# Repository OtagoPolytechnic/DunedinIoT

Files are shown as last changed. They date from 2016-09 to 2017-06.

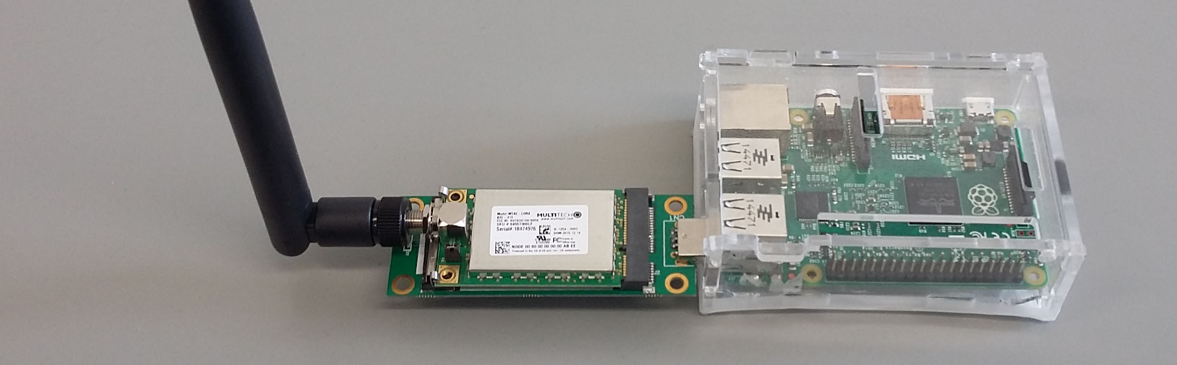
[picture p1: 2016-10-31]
images/gateway_hardware.jpg

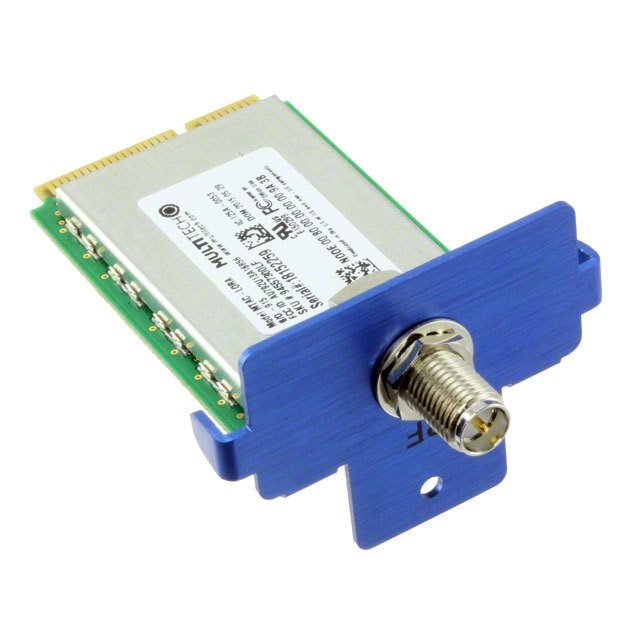
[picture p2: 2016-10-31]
images/mCard.jpg

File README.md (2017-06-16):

---
layout: default
title: Home
---

# IoT Dunedin

## What is the Internet of Things?
The Internet of Things is the inter-networking of devices such as smart devices, sensors, software, and other items embedded with electronics.
Connecting these devices to a network creates the Internet of Things and enables the collection and exchange of data between devices and server. 
This data can then be used accessed and used by an end user. Although very similar, this is not to be confused by wifi. The IoT uses slightly 
different technology to achieve *this*. Our Iot solution is implemented using LoRaWAN.

## LoRaWAN Network
LoRaWAN is a low-power, long-range wide area network standard devised by the LoRa Alliance.
It is intended for long-life, battery operated sensor devices to communicate sensed data to a central server via one or more internet-connected gateway devices capable of receiving radio transmissions.

## Our Goal:
To research and develop an open LoRaWAN consisting of one or more gateway devices, multiple sensor devices, and a central server. All of this in the central Dunedin area, to provide access to user data for use in custom mobile/web/desktop applications.

### Current Status:
Testing prototype working, but not on the right frequencies. 

### Future Plan:
Move prototype to new hardware and onto the right frequencies. (Next semester).

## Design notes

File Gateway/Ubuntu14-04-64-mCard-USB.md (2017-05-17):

# Ubuntu Trusty (14.04) with Lora mCard - Preparing a test gateway host in a VirtualBox VM

## Prep:
* Install VirtualBox.
* In VirtualBox VM manager, install an Ubuntu 14.04 install as usual. Server version is fine unless you want a GUI.
* Plug Mcard/USB into PC.
* Select virtual machine, click settings, click USB, add a USB device filter for FDTI device.

-----------------

## Set up:
1. Install 32 bit ftdi drivers to talk to the mCard:

`sudo apt-get install libftdi1:i386`

-----------------

2. Install 32 SSL 1.0.2 installed, supplied by 3rd party repository:

`openssl version -a`

`sudo add-apt-repository ppa:0k53d-karl-f830m/openssl`

`sudo apt-get update`

`sudo apt-get install openssl`

`openssl version -a`

-----------------

3. Download the libmpsse source and compile/install :

`sudo apt-get install swig libftdi-dev python-dev`

`wget https://github.com/devttys0/libmpsse/archive/master.zip -O libmpsse.zip`

`unzip libmpsse.zip`

`cd libmpsse-master`

`cd src`

`./configure`

`make`

`sudo make install`

-----------------

4. Unplug card, power off VM, replug card, and power on VM.

The gateway is now ready for packet forwarding software, for example:

To test with Loriot:

 Open a terminal and get the Loriot binary address (it's different for every server, this gateway is registered on us1.loriot.io )

`sudo mkdir /lrt`

`sudo chmod 777 /lrt`

`cd /lrt`

`wget http://us1.loriot.io/home/gwsw/loriot-linux-x64-mcard-USB-0-latest.bin -O loriot-gw`

`chmod +x loriot-gw`

`cd /lrt`

`sudo ./loriot-gw -f`

---------------

## Notable problems:
* Without SSL 1.0.2 there will be an error.
* Without install the i386 (32 bit) FTDI drivers there wiill be an error message about a missing .so file.
* Gateway terminal will log 404 errors if gateway MAC is not properly  registered with Loriot (or other provider).
* There was an error message and LIBMPSSE code saying "you could be running an incompatible version of the binary" after installing another LIBMPSSE version. That version was replaced with the version above and after restarting the hardware the gateway was active.

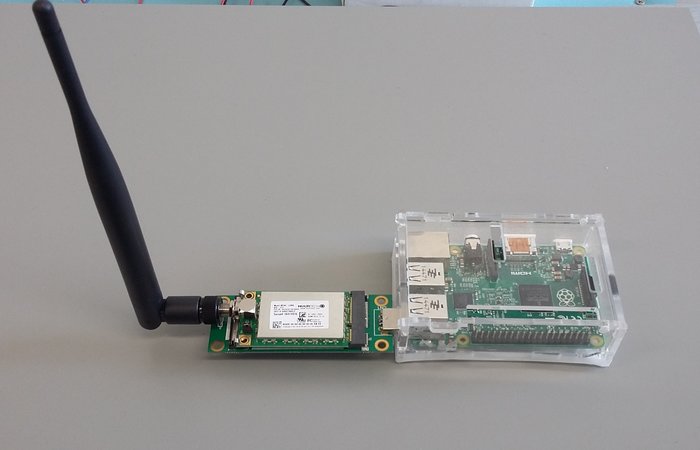
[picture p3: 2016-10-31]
images/GW_tmb.jpg

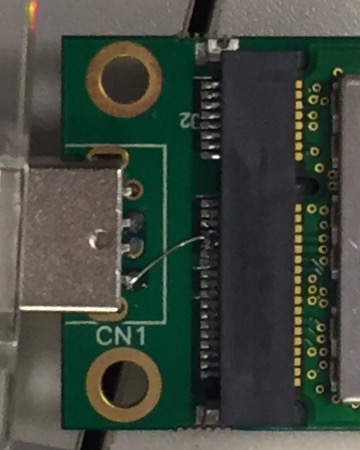
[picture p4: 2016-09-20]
images/gateway1.jpg

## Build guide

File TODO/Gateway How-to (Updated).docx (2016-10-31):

Creating a LoRaWAN Gateway

There are many options you can pursue when choosing the hardware to use for LoRaWAN applications. You can choose to simply buy the pre-made TTN Gateway directly from TTN themselves, or you can choose a cheaper, more DIY route.

For our LoRaWAN Gateway we chose to build and configure our own. This quick how-to describes how our gateway was created, from choosing the correct parts to installing software.

Choosing the Correct Hardware

When building the gateway for yourself you need to make sure the hardware you choose is compatible. There are multiple options, but we will only focus on the option that we pursued.

We need the following hardware before we can get started:

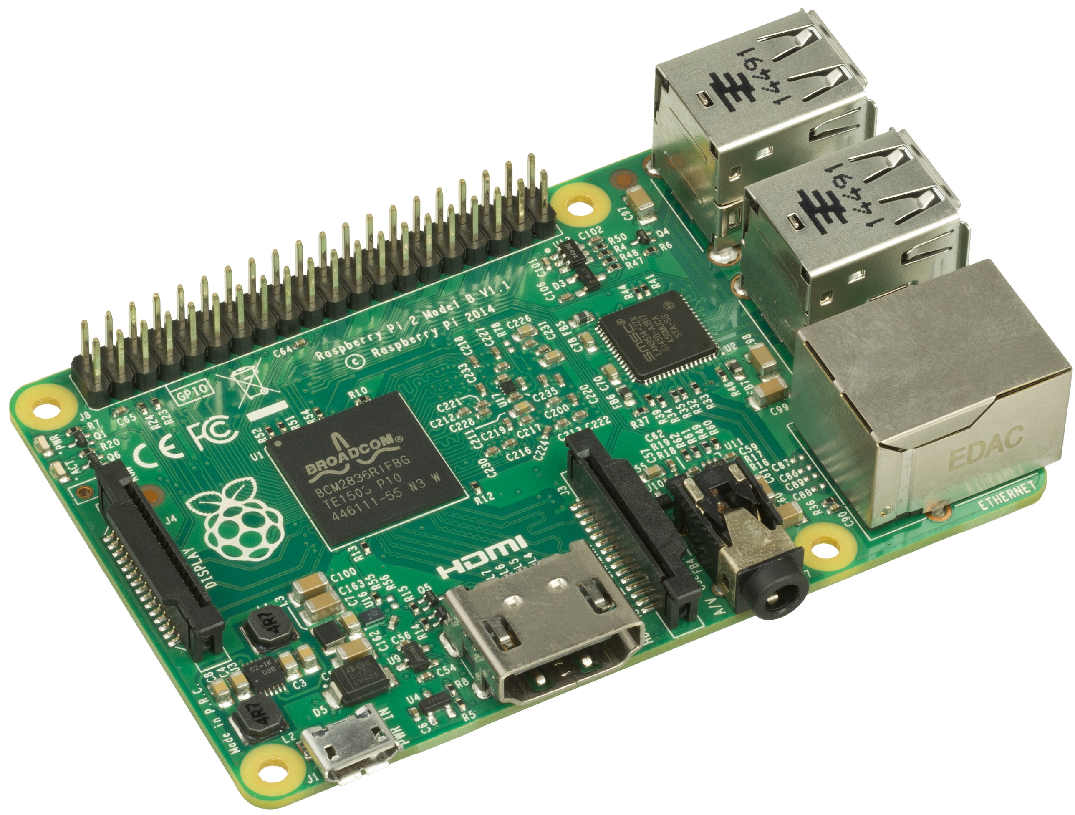
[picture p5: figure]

- Raspberry Pi

A Raspberry Pi is used as the main controller for the gateway. It will hold and run our software, and will be connected to the rest of our devices. Any Raspberry Pi model will do, but faster is generally better. We used a Raspberry Pi 1, Model B. This is one of the earlier models, but had enough speed to be able to keep up. We would recommend either a Raspberry Pi 2 or Raspberry Pi 3. Differences between the models can be found here. (https://en.wikipedia.org/wiki/Raspberry_Pi)

You can buy these boards from a variety of places around New Zealand, or you can import from overseas. I highly recommend element14 (http://nz.element14.com/raspberrypi-boards), As they are cheap and offer free delivery if your order is over $45.

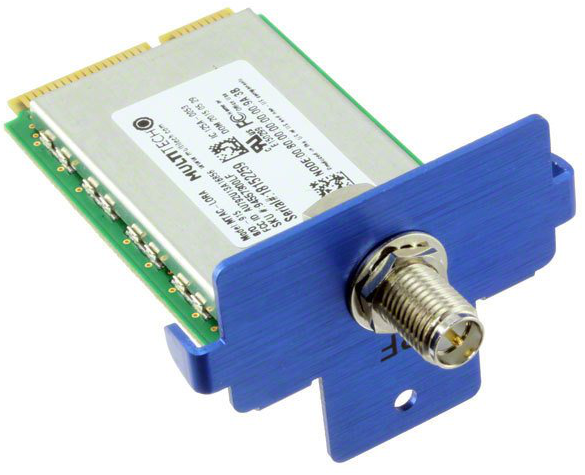
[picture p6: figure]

- Multitech mCard-LoRa

This is the sender and receiver of LoRaWAN packets, without this hardware the gateway will not be able to talk to our nodes. This device comes with an antenna, and is PCIe compatible.

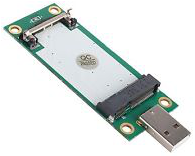
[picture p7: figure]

- USB to Mini-PCIe Convertor

This adaptor is necessary to connect the mCard to the Raspberry Pi, as the Pi does not have a Mini-PCIe slot itself.

Installing and Running Software

To be able to install the gateway software on the Raspberry Pi, the Pi itself needs to be set up. We used Raspbian (https://www.raspberrypi.org/downloads/raspbian/), a version of Debian designed to run on a Raspberry Pi’s architecture. We won’t cover how to install Raspbian (https://www.raspberrypi.org/documentation/installation/installing-images/README.md), as there is already a lot of documentation out there for it and it can be installed incredibly quickly and easily through NOOBS for Raspberry Pi.

Once you have a working version of Raspbian on your Raspberry Pi, you need to get the gateway software. There are multiple parts of software we need, so follow the next instructions carefully:

sudo apt-get update

sudo apt-get install git --assume-yes

sudo apt-get install libftdi-dev --assume-yes

cd ~

wget http://libmpsse.googlecode.com/files/libmpsse-1.3.tar.gz

tar zxvf libmpsse-1.3.tar.gz

cd libmpsse-1.3/src

./configure --prefix=/usr --disable-python

make

sudo make install

cd /etc/udev/rules.d

sudo wget https://raw.githubusercontent.com/mirakonta/lora_gateway/master/libloragw/99-libftdi.rules

sudo udevadm control --reload-rules

sudo udevadm trigger

sudo adduser pi plugdev

cd ~

Now we have our dependencies we can download and compile the LoRaWAN Gateway Software:

mkdir ~/lora

cd ~/lora

mkdir exec

git clone https://github.com/mirakonta/lora_gateway.git

git clone https://github.com/mirakonta/packet_forwarder.git

cd ~/lora/lora_gateway

make clean all

cd ~/lora/packet_forwarder

make clean all

cp ~/lora/packet_forwarder/basic_pkt_fwd/basic_pkt_fwd ~/lora/exec/

cp ~/lora/packet_forwarder/basic_pkt_fwd/*.json ~/lora/exec/

cd ~/lora/exec

The gateway code is now compiled and ready to go. To run the gateway, simply run the command:

sudo ./basic_pkt_fwd

Running the Gateway Automatically (Headless)

After installing and configuring the gateway using the above steps, you may find it desirable to have the gateway software run automatically, rather than logging in to the Pi and starting it manually.

To do this, we would use Cron (https://en.wikipedia.org/wiki/Cron). Cron is a job scheduler which is built-in to many versions of Linux. Do the following to start the LoRa gateway software at boot:

After logging in to the Pi, type: “sudo crontab -e”

Use the down arrow to move to the end of the file.

Type “@reboot ./[location of basic_pkt_fwd]”.

Save the file.

“@reboot” tells Cron to run the job at boot.

Restart the gateway. If the software runs at startup, you have successfully set everything up. If not, you may need to check the crontab file or recheck the directory the file is in for any mistakes.

Troubleshooting Hardware (optional)

Something you may need to do is a small hardware modification on the Mini-PCIe adaptor to provide more power to the antennae. We didn’t end up having to do it, as our board worked anyway. However, if you have completely set up the gateway and it still doesn’t seem to be working, you can try this optional step.

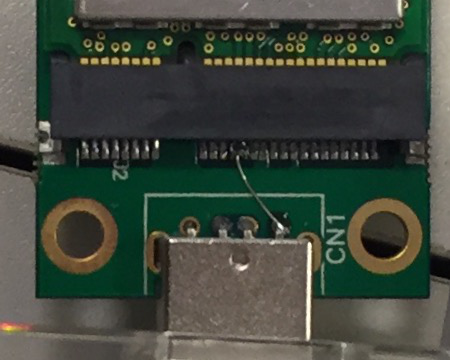
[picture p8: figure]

Sometimes it may be necessary to provide extra power to a couple of the pins on the adaptor. To do this we need to solder a wire from the 5V pin on the USB connector to pins 23 and 25 of the PCIe connector. Below is a picture of the completed modification:

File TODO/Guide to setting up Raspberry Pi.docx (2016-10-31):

Guide to setting up Raspberry Pi

What you will need:

- SD Card (8GB) pre-installed with Raspberry Pi NOOBS
- Display cable – HDMI to DVI cable
- Keyboard and Mouse
- Any standard USB keyboard and mouse works.
- Power supply
- Pi is powered by a USB Micro power supply
- You will need a good-quality power supply that can supply at least 2A at 5V for the Model 3B
- Ethernet cable

How to get NOOBS:

- NOOBS is available for download on the Raspberry Pi website
- https://www.raspberrypi.org/downloads/noobs/
- NOOBS (Offline and network install)
- “Download ZIP”

How to Install NOOBS on an SD Card:

Once you’ve downloaded the NOOBS zip file, you will need to copy the contents to a formatted SD card on your computer.

- Format and SD card (8GB) as FAT
- Extract files and contents from the NOOBS zip file.
- Copy extracted file at the root of directory of the SD card.
- (Note: copy files without its folder)

Installing NOOBS:

- Insert SD card into Raspberry Pi
- Power up Raspberry Pi
- On first boot, the FAT partition will automatically resized.
- Selecting OS: “Raspbian [RECOMMENDED]”

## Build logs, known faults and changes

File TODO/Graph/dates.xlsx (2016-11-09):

date | temp | time
2016-11-02 | 23 | 0:00:00
2016-11-02 | 4 | 2:00:00
2016-11-02 | 18 | 4:00:00
2016-11-02 | 14 | 6:00:00
2016-11-02 | 12 | 8:00:00
2016-11-02 | 6 | 10:00:00
2016-11-02 | 6 | 12:00:00
2016-11-02 | 0 | 14:00:00
2016-11-02 | 0 | 16:00:00
2016-11-02 | 4 | 18:00:00
2016-11-02 | 8 | 20:00:00
2016-11-02 | 14 | 22:00:00
2016-11-03 | 9 | 0:00:00
2016-11-03 | 2 | 2:00:00
2016-11-03 | 5 | 4:00:00
2016-11-03 | 17 | 6:00:00
2016-11-03 | 17 | 8:00:00
2016-11-03 | 15 | 10:00:00
2016-11-03 | 20 | 12:00:00
2016-11-03 | 14 | 14:00:00
2016-11-03 | 14 | 16:00:00
2016-11-03 | 17 | 18:00:00
2016-11-03 | 13 | 20:00:00
2016-11-03 | 6 | 22:00:00
2016-11-04 | 18 | 0:00:00
2016-11-04 | 25 | 2:00:00
2016-11-04 | 13 | 4:00:00
2016-11-04 | 15 | 6:00:00
2016-11-04 | 4 | 8:00:00
2016-11-04 | 2 | 10:00:00
2016-11-04 | 24 | 12:00:00
2016-11-04 | 12 | 14:00:00
2016-11-04 | 0 | 16:00:00
2016-11-04 | 21 | 18:00:00
2016-11-04 | 15 | 20:00:00
2016-11-04 | 6 | 22:00:00
2016-11-05 | 5 | 0:00:00
2016-11-05 | 5 | 2:00:00
2016-11-05 | 7 | 4:00:00
2016-11-05 | 6 | 6:00:00
2016-11-05 | 6 | 8:00:00
2016-11-05 | 20 | 10:00:00
2016-11-05 | 10 | 12:00:00
2016-11-05 | 8 | 14:00:00
2016-11-05 | 19 | 16:00:00
2016-11-05 | 25 | 18:00:00
2016-11-05 | 19 | 20:00:00
2016-11-05 | 1 | 22:00:00
2016-11-06 | 1 | 0:00:00
2016-11-06 | 19 | 2:00:00
2016-11-06 | 2 | 4:00:00
2016-11-06 | 22 | 6:00:00
2016-11-06 | 22 | 8:00:00
2016-11-06 | 13 | 10:00:00
2016-11-06 | 20 | 12:00:00
2016-11-06 | 16 | 14:00:00
2016-11-06 | 21 | 16:00:00
2016-11-06 | 15 | 18:00:00
2016-11-06 | 10 | 20:00:00
2016-11-06 | 9 | 22:00:00
2016-11-07 | 3 | 0:00:00
2016-11-07 | 17 | 2:00:00
2016-11-07 | 24 | 4:00:00
2016-11-07 | 15 | 6:00:00
2016-11-07 | 13 | 8:00:00
2016-11-07 | 23 | 10:00:00
2016-11-07 | 16 | 12:00:00
2016-11-07 | 13 | 14:00:00
2016-11-07 | 18 | 16:00:00
2016-11-07 | 8 | 18:00:00
2016-11-07 | 7 | 20:00:00
2016-11-07 | 6 | 22:00:00
2016-11-08 | 13 | 0:00:00
2016-11-08 | 12 | 2:00:00
2016-11-08 | 11 | 4:00:00
2016-11-08 | 11 | 6:00:00
2016-11-08 | 12 | 8:00:00
2016-11-08 | 13 | 10:00:00
2016-11-08 | 16 | 12:00:00
2016-11-08 | 20 | 14:00:00
2016-11-08 | 16 | 16:00:00
2016-11-08 | 19 | 18:00:00
2016-11-08 | 16 | 20:00:00
2016-11-08 | 16 | 22:00:00
2016-11-09 | 14 | 0:00:00
2016-11-09 | 14 | 2:00:00
2016-11-09 | 14 | 4:00:00
2016-11-09 | 13 | 6:00:00
2016-11-09 | 14 | 8:00:00
2016-11-09 | 15 | 10:00:00
2016-11-09 | 15 | 12:00:00
2016-11-09 | 16 | 14:00:00
2016-11-09 | 16 | 16:00:00
2016-11-09 | 15 | 18:00:00
2016-11-09 | 13 | 20:00:00
2016-11-09 | 12 | 22:00:00
2016-11-10 | 11 | 0:00:00
2016-11-10 | 11 | 2:00:00
2016-11-10 | 10 | 4:00:00
2016-11-10 | 10 | 6:00:00
2016-11-10 | 11 | 8:00:00
2016-11-10 | 13 | 10:00:00
2016-11-10 | 13 | 12:00:00
2016-11-10 | 13 | 14:00:00
2016-11-10 | 13 | 16:00:00
2016-11-10 | 13 | 18:00:00
2016-11-10 | 12 | 20:00:00

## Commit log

2016-04-15 Light sensor 1
2016-11-09 Raspberry Pi
2016-11-09 Graph Scripting
    [dates.xlsx]
2016-11-09 Datepicker Error
    [dates.xlsx]
2017-04-28 Trying to Archive all old stuff
    [dates.xlsx]
2017-06-12 added room sensor individual part examples
    [RTC_DATETIME_LED_wiring.fzz, RTC_sleeping_LED_wiring.fzz, TempHumid.fzz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]
2017-06-12 switch back to cayman theme
2017-08-09 Added links to Development dropdown button
2018-06-19 Removed all old conent, as we have migrated to a new website. Please see: https://bit-project-sites.pages.op-bit.nz/iot/
    [Dragino868TempHumid.fzz, Dragino868TempHumidLDR.fzz, RTC_DATETIME_LED_wiring.fzz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]
2018-06-19 Readded site again.... bad timing it would seem
    [Dragino868TempHumid.fzz, Dragino868TempHumidLDR.fzz, RTC_DATETIME_LED_wiring.fzz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]
2018-06-26 Removed old website. Replaced with a simple theme which points to the new website. Included a 404 page to also redirect users.
    [Dragino868TempHumid.fzz, Dragino868TempHumidLDR.fzz, RTC_DATETIME_LED_wiring.fzz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]
